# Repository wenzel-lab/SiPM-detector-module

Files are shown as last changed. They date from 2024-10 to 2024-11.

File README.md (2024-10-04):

# Open Source Hardware Silicon Photomultiplier (SiPM) Module 

Introduction... work in progress...

Follow us! [#twitter](https://twitter.com/WenzelLab), [#YouTube](https://www.youtube.com/@librehub), [#LinkedIn](https://www.linkedin.com/company/92802424), [#instagram](https://www.instagram.com/wenzellab/), [#Printables](https://www.printables.com/@WenzelLab), [#LIBREhub website](https://librehub.github.io), [#IIBM website](https://ingenieriabiologicaymedica.uc.cl/en/people/faculty/821-tobias-wenzel)

## Contribute

This is an open project in the Wenzel Lab in Santiago, Chile. If you have any suggestions to improve it or add any additional functions make a pull-request or [open an issue](https://github.com/wenzel-lab/SiPM-detector-module/issues/new).
For interactions in our team and with the community applies the [GOSH Code of Conduct](https://openhardware.science/gosh-2017/gosh-code-of-conduct/).

## License

[CERN OHL 2W](LICENSE) © FRANCISCO JAVIER MARTINEZ CATALDO and Tobias Wenzel. This project is Open Source Hardware - please acknowledge us when using the hardware or sharing modifications.

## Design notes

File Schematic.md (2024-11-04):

# Schematic of Circuit

For the preamplification stage, there are two options: design a transimpedance amplifier (TIA) or an inverting amplifier. Based on this, an operational amplifier is selected considering the following 3 criteria: *a unity-gain bandwidth of at least 1 GHz, input voltage noise less than 5 nV/√Hz, and a stable gain AV ≥ 10*. An operational amplifier with these characteristics can be used to amplify the SiPM signal with a pulse width of a few tens of nanoseconds without introducing significant noise at the 50 Ω output.

**1.- Transimpedance Amplifier TIA:** A TIA is an amplifier that converts an input current signal into a voltage signal. It is commonly used in applications where the input signal is current, such as in SiPM. For its design, the following equations must be considered to calculate the feedback capacitance Cf and the cutoff frequency Fc at a given gain. For more information you can review this [article](https://www.ti.com/lit/an/sboa122/sboa122.pdf). 

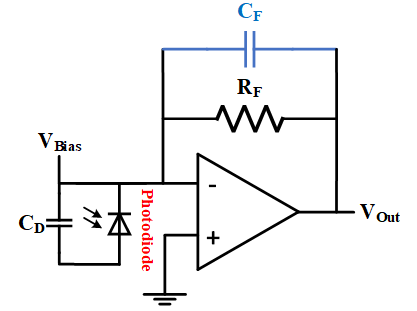
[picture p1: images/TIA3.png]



>! **Caution** 
>!
>! From the equations, it can be determined that higher gain results in lower bandwidth and a smaller optimal value for Cf, which is recommended to be greater than 1 pF. Values smaller than this begin to be significantly affected by the parasitic capacitances of the PCB. Additionally, you must consider the minimum gain at which the selected amplifier is stable.

**2.- Inverting Amplifier:** An inverting amplifier is a configuration where the input signal from SiPM is applied to the inverting input of the operational amplifier, while the non-inverting input is grounded. For its design, the following equations must be considered to calculate the feedback resistance Rf and bandwidth. The higher the gain, the lower the bandwidth. For a gain of AV = 10, the bandwidth is reduced to 150 MHz if GBP of amplifier is 1.5GHz. 

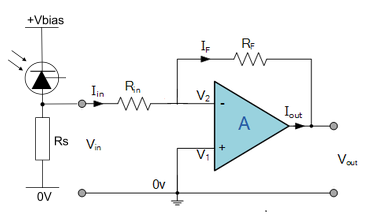
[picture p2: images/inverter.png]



>i **Note** 
>i
>i You can add a feedback capacitance Cf in parallel with the feedback resistor Rf. This way, the amplifier will also function as a low-pass filter, with a cutoff frequency Fc=1/(2PiRfCf). It is recommended to use the amplifier with a ±Vcc supply. Otherwise, if only a +Vcc source is used, you must generate an offset and decouple the amplifier's input from the SiPM output with a capacitor.

**3.- Non-inverting amplifier:** The non-inverting amplifier has a higher gain than the inverting amplifier, but its bandwidth is limited. For the proper use of the amplifier, you must cancel the bias currents by incorporating a resistance Rt at the + input pin of the amplifier, which is calculated using the following equation.

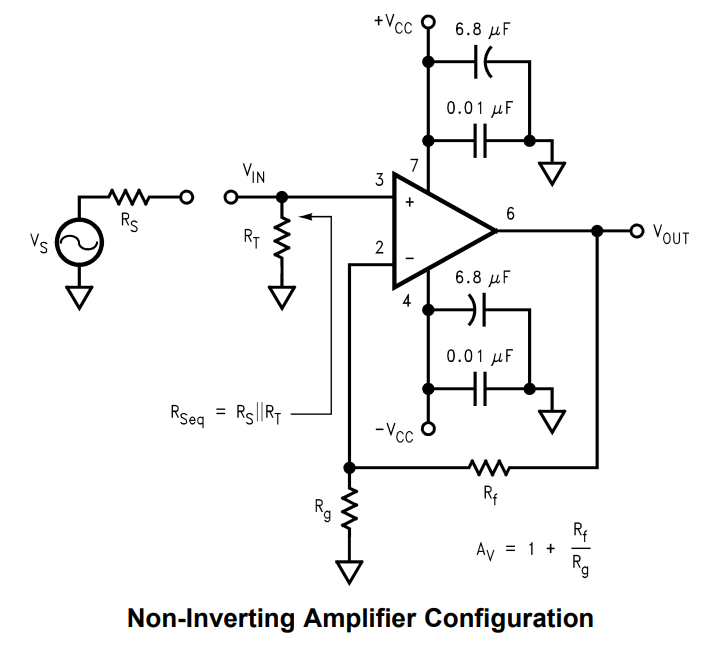
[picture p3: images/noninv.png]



>i **Note** 
>i
>i For the inverting amplifier, it is also recommended to add a resistor at the + pin to ground to cancel the bias currents. This resistor is obtained from Rf//Rin.

**4.- Final design:** A circuit is designed to allow testing of either the TIA topology or an inverting amplifier in the preamplification stage, followed by an amplification stage with a non-inverting amplifier. You can download the schematic from [here](doc/Sheet_SiPM.SchDoc). (It includes the power supply circuit, as it will be part of the same PCB).

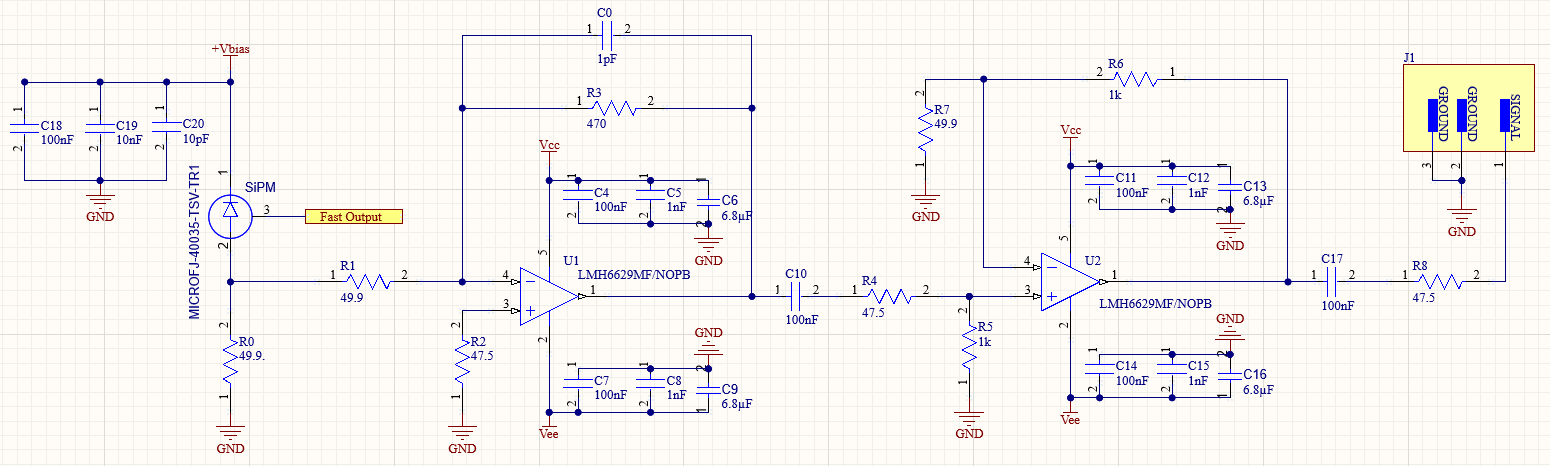
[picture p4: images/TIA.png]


|  Topology | R0[Ω] | R1[Ω] | R2[Ω] | R3[Ω] | C0 [pF] |
|:---:|:---:|:---:|:---:|:---:|:---:|
| TIA | NC |  0  | 10 | 1k | 1 |
| Inverter |  49.9 |  49.9  | 47.5 | 511 | 2 |

>i **Note** 
>i
>i The amplification stage can be omitted if from preamplification stage the pulses have enough amplitude. This depends on the number of photons that will hit the sensitive area of the SiPM and the gain of the photomultiplier, which is proportional to the size of the pixel.

Additionally, the circuit was simulated with the real components to determine the stability of the signal amplifier of the SiPM under different conditions. You can download the PSpice project by clicking [here](doc/project_sipm-PSpiceFiles.rar) 

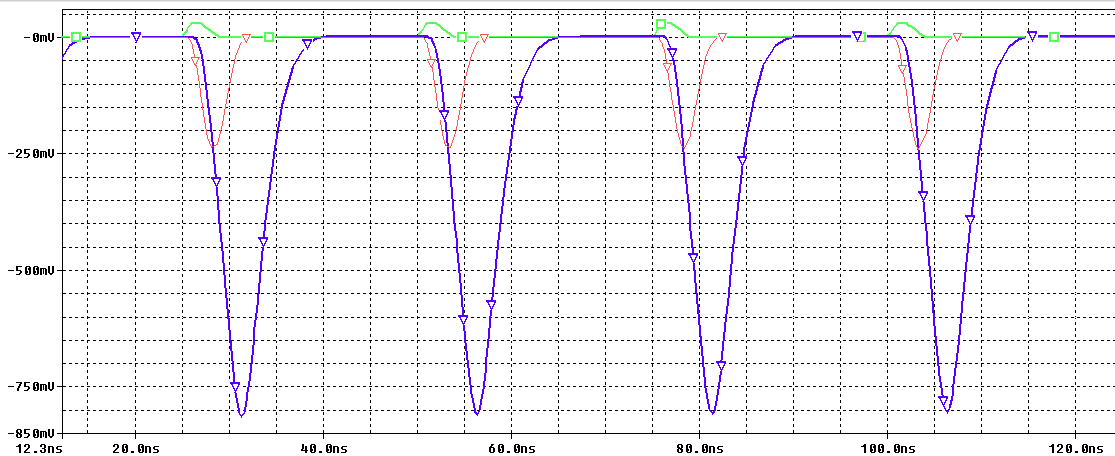
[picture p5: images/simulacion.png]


The green curve corresponds to the SiPM pulse, the red curve is the output of the preamplifier, and the blue curve is the output of the non-inverting amplifier. **Consider that the amplitude of the SiPM pulse will depend on the light incident on its sensitive area.**

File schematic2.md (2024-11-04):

# General Schematic

The circuit is divided into 2 sections detailed below. You can download the schematic from [here](doc/Sheet_SiPM.SchDoc). (It includes the readout circuit, as it will be part of the same PCB).

## 1. Boost Converter

The [MP3216](https://www.monolithicpower.com/en/documentview/productdocument/index/version/2/document_type/Datasheet/lang/en/sku/MP3216/document_id/1113) integrated circuit is chosen as the boost converter for this design. Key components such as inductor 33uH, capacitors, and feedback resistors are used to regulate and stabilize the voltage. The MP3216 is well-suited for compact designs and efficient power conversion, ensuring a steady voltage supply to the SiPM bias system.

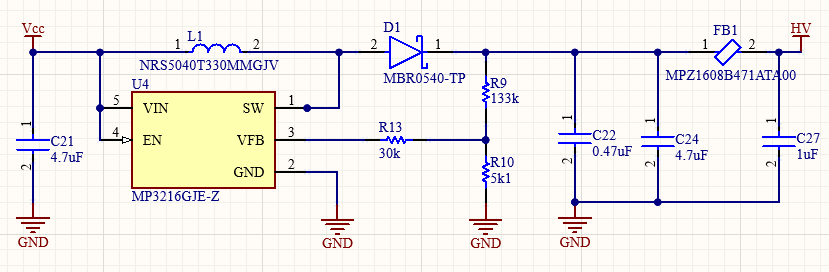
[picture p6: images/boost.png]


>i **Note** 
>i
>i An RC filter is added at the output of the converter to reduce voltage ripple to 1mVpp. Instead of a standard resistor, a ferrite model [MPZ1608B](https://product.tdk.com/en/system/files/dam/doc/product/emc/emc/beads/catalog/beads_commercial_power_mpz1608_en.pdf) is used. Its DC resistance is only 150mΩ, and at the 1MHz switching frequency, its impedance is approximately 75Ω.

## 2. Controllable Amplifier 

The cost-optimized operational amplifier model [TLV9351](https://www.ti.com/lit/ds/symlink/tlv9354.pdf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)  is selected, which can be powered with up to 40V (HV point). It is configured to have a gain of x10 with respect to the voltage Vctrl. Then, an RC filter is added to eliminate high-frequency noise to obtain an appropriate bias voltage (Vbias point) for the SiPM. Finally, a buffer model [MCP6006](https://ww1.microchip.com/downloads/aemDocuments/documents/APID/ProductDocuments/DataSheets/MCP6006-6R-6U-7-9-Data-Sheet-20006411B.pdf) with high input impedance is included, allowing monitoring of the high voltage (V_HV point).  
 
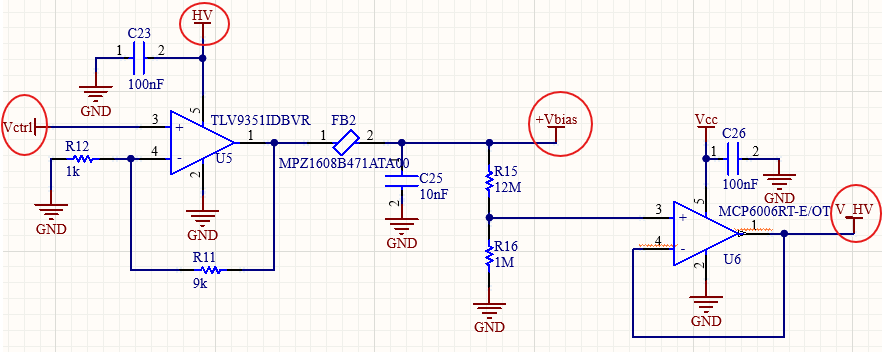
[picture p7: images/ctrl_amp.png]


The voltage ranges for each point are as follows:

|  Vctrl [V] | HV [V] | +Vbias [V] | V_HV [V] |
|:---:|:---:|:---:|:---:|
| 0 - 3.3 | 33 | 0 - 33 | 0 - 2.54 |

>
>!! **Warning** 
>!!
>!! You should limit the control voltage Vctrl depending on the maximum operating voltage of the selected SiPM. For example, if the maximum operating voltage is 30.7V, then the Vctrl voltage should not exceed 3.07V. Additionally, for high voltage monitoring, it is recommended to use an ADC with at least 12 bits, allowing Vbias adjustments with a resolution of ±10mV.
>

>i **Note** 
>i
>i Consider that the gain of SiPMs is dependent on ambient temperature, with a Vbias adjustment factor between 20-30mV/°C. Specifically, if the temperature increases, the gain will decrease, so you should to know what voltage amplitudes you will consider in your experiment. If you want to differentiate fluorescence levels, you should include temperature monitoring and adjust the control voltage Vctrl accordingly. 
>

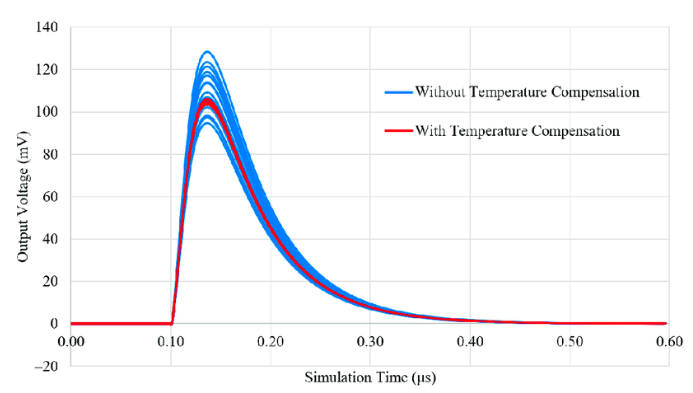
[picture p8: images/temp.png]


***Reference:** Nile E. J. Dixon et al. "Compact Back-End Electronics with Temperature Compensation and Efficient Data Management for In Situ SiPM-Based Radiation Detection",  Sensors 2023.*

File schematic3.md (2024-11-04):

# TSV Pin Adapter board

An adapter board for the SiPM is designed to allow easy connection between the silicon photomultiplier 4x4mm TSV(Through Silicon Via) and the readout. You can download the schematic and the PCB layout from [here](doc/adapt_board.zip)

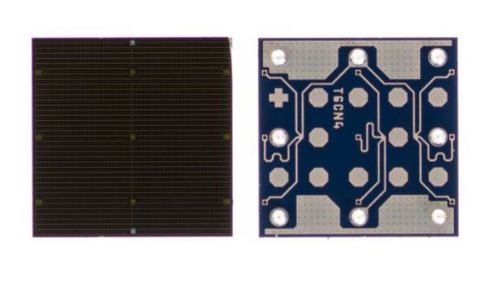
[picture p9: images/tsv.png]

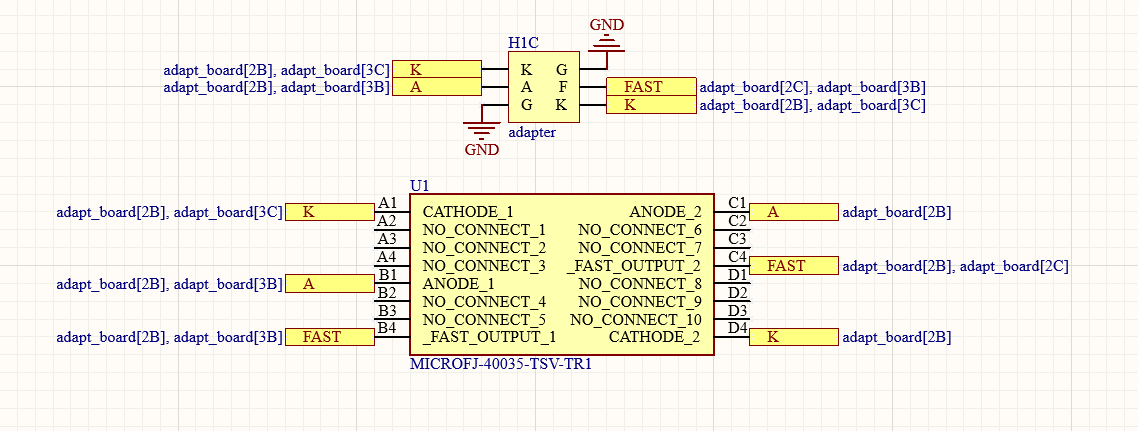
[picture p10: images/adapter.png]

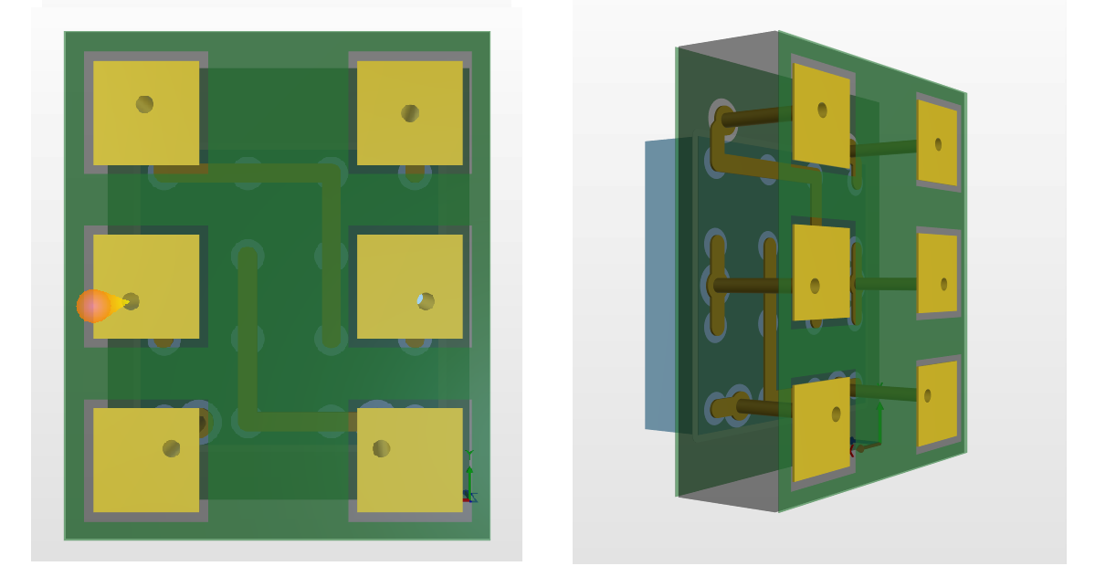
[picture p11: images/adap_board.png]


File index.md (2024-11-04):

# SiPM Module detector

This is our open-source hardware and custom electronics solution for SiPM module detector. It is used as part of "Ritmos,” our Real-time Technology for Microfluidic Droplet Sorting, as well as other microfluidics development projects. We implemented a board that includes the readout system to amplify SiPM signals to a measurable voltage with ultra-low noise, allowing the detection of a single photon. Additionally, a controllable voltage source is included, which enables the SiPM to be biased at different operating voltages. The readout provides a fast output with higher temporal resolution and a standard 50-ohm output with greater energy resolution. The SiPM detector module works with a single +5V power supply and a control voltage (Vctrl) in the range of 0-3.3V, allowing adjustment of the final SiPM bias voltage.

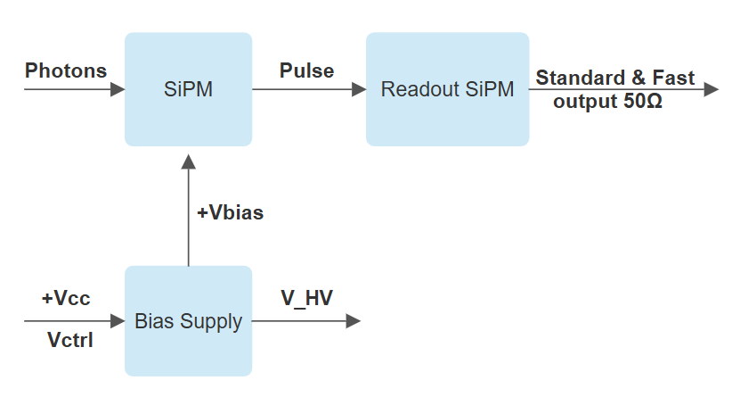
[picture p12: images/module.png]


To explore the documentation, please use the links below:

- [SiPM](testpage7.md)
	- [Go to TSV_Pin_Adapter_board](schematic3.md#TSV_Pin_Adapter_board)
- [Readout SiPM](testpage1.md)
	- [Go to Schematic_Redout_SiPM](Schematic.md#Schematic_Redout_SiPM)
- [Bias Supply](testpage5.md)
	- [Go to Schematic_Controllable_Bias_Supply](schematic2.md#Controllable_Schematic_Bias_Supply)

## References

>i **Note:** This system builds upon resources from:
>i 
>i 1.- *Giancarlo Barbarino et al. "Silicon Photo Multipliers Detectors Operating in Geiger Regime: an Unlimited Device for Future Applications", [Photodiodes](https://www.intechopen.com/chapters/17225) (2011)*
>i
>i 2.- *Brae V Petersen et al. "Silicon Photomultipliers as a Low-Cost Fluorescence Detector for Capillary Electrophoresis", [Anal Chem](https://pmc.ncbi.nlm.nih.gov/articles/PMC7728455/#SD1) 2020*

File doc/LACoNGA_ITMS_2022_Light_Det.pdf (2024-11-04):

## Light Detection with SiPMs

by Dennis Cazar Ramírez

March 23, 2022

by Dennis Cazar Ramírez | Light Detection with SiPMs | March 23, 2022 | 1 / 22

## Contents

1 | Light - Matter Interaction Cherenkov Radiation Photoelectric effect
2 | Photomultipliers Basic Concepts Pros and Cons
3 | SiPMs Basic Concepts Photo-electron Spectrum Performance Parameters Afterpulsing Dark Count Rate Optical Crosstalk
4 | Conclusions
by Dennis Cazar Ramírez | Light Detection with SiPMs | March 23, 2022 | 2 / 22

## Light - Matter Interaction

Introduction

Let´s focus in two scenarios:

Charged particles vs matter: Ionization, Cherenkov Effect, Bremsstrahlung
Photons vs matter: Photoelectric Effect, Compton effect, pair production

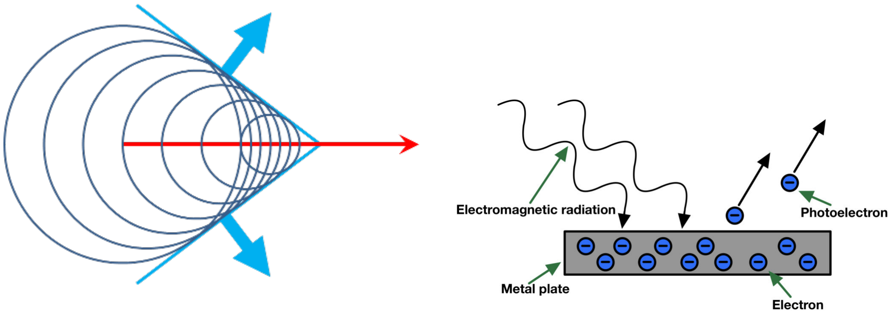
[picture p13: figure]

Cherenkov effect produces light (UV photons) while Photoelectric effect produces photo-electrons

by Dennis Cazar Ramírez | Light Detection with SiPMs | March 23, 2022 | 3 / 22

## Cherenkov Effect

Basic Concepts

Cherenkov radiation is electromagnetic radiation emitted when a charged particle (such as a muon) passes through a dielectric medium at a speed greater than the speed of light in that medium.

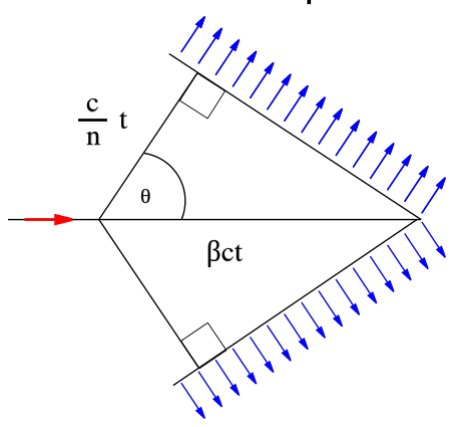
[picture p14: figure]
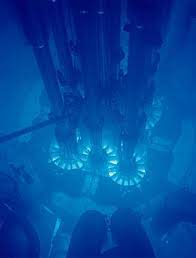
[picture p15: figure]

Its cause is similar to the cause of a sonic boom, the sharp sound heard when faster-than-sound movement occurs.
β the ratio between the speed of the particle and the speed of light The emitted light waves travel at speed ve = c/n
the emission angle results in cosθ = 1/nβ
by Dennis Cazar Ramírez | Light Detection with SiPMs | March 23, 2022 | 4 / 22

## Cherenkov Effect

Applications

A Water Cherenkov Detector WCD is used to detect relativistic particles (muons, electrons even neutrinos)

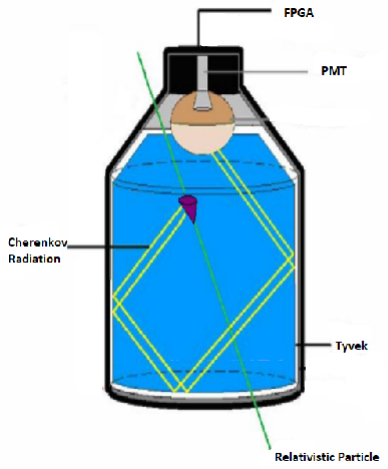
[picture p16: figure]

Cherenkov radiation is detected by a Photomultiplier PMT and converted into electric current
This signal is digitized and processed by an FPGA
by Dennis Cazar Ramírez | Light Detection with SiPMs | March 23, 2022 | 5 / 22

## Photoelectric effect

Basic Concepts

The photoelectric effect is the emission of electrons when electromagnetic radiation, such as light, hits a material. Electrons emitted in this manner are called photo-electrons.
In 1905, Einstein proposed a theory of the photoelectric effect using a concept first put forward by Max Planck that light consists of tiny packets of energy known as photons or light quanta.

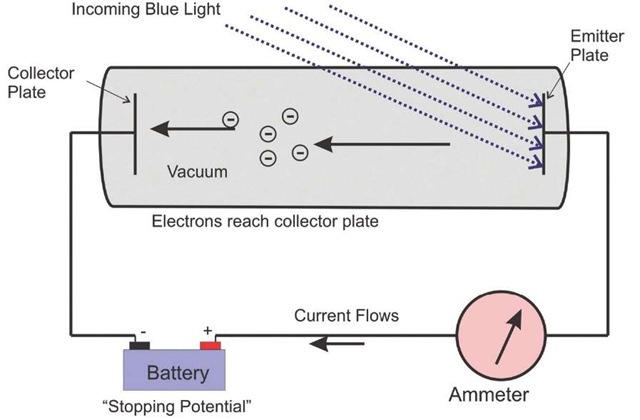
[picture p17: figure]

Kinetic energy of the emitted photo-electron is K = h(f − fo

The emitted photo-electron can be accelerated by an external electric field

by Dennis Cazar Ramírez | Light Detection with SiPMs | March 23, 2022 | 6 / 22

## Photomultipliers

Basic Concepts

These are extremely light-sensitive vacuum tubes with a coated photocathode inside the envelope.
By means of a series of electrodes (dynodes) at ever-higher potentials, these electrons are accelerated and substantially increased in number through secondary emission to provide a readily detectable output current.

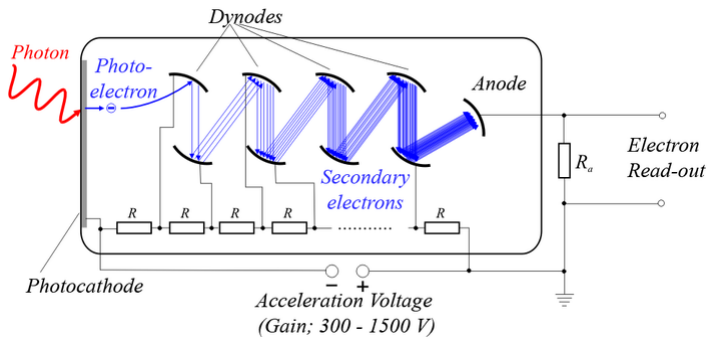
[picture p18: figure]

Photomultipliers are still commonly used wherever low levels of light must be detected

by Dennis Cazar Ramírez | Light Detection with SiPMs | March 23, 2022 | 7 / 22

## Photomultipliers

Pros and Cons

Pros
PMTs are extremely sensitive detectors of light (UV, visible, and near-IR)
PMTs amplification is as much as 10⁸
(i.e. 160 dB!!!)
They have low noise and fast response

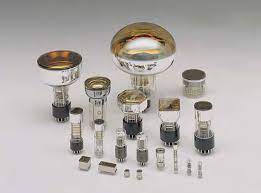
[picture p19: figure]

Cons
PMTs need High Voltage HV (300 to 2000 V) sources to operate. PMTs are sensitive to Magnetic Fields
Very expensive and delicate
by Dennis Cazar Ramírez | Light Detection with SiPMs | March 23, 2022 | 8 / 22

## Silicon Photo-multipliers

Basic concepts

The Silicon Photomultiplier (SiPM) is a sensor that addresses the challenge of sensing, timing and quantifying low-light signals down to the single-photon level
The SiPM features low-voltage operation, insensitivity to magnetic fields, mechanical robustness and excellent uniformity of response

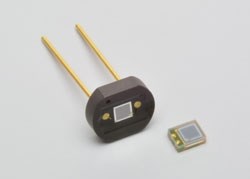
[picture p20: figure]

When a photon travels through silicon, it may be absorbed and transfer energy to a bound electron. This absorbed energy causes the electron to move from the valence band into the conduction band, creating an electron-hole pair.

by Dennis Cazar Ramírez | Light Detection with SiPMs | March 23, 2022 | 9 / 22

## Silicon Photo-Multipliers

Photodiodes

A photodiode is formed by a silicon p-n junction that creates a depletion region that is free of mobile charge carriers.

When a photon is absorbed in silicon it will create an electron-hole pair.
Applying a reverse bias to a photodiode sets up an electric field across the depletion region that will cause these charge carriers to be accelerated towards the anode (holes), or cathode (electrons).

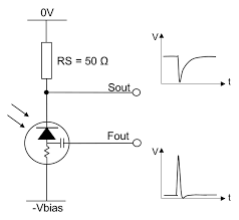
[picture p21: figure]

by Dennis Cazar Ramírez | Light Detection with SiPMs | March 23, 2022 | 10 / 22

## Silicon Photomultipliers

Schematic

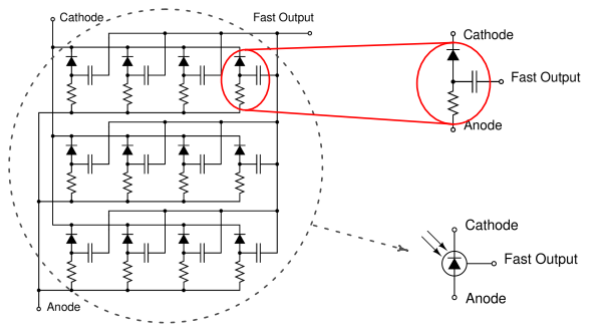
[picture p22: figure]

Simplified Circuit Schematic of a SiPM showing each Microcell which is Composed of the SPAD (Single Photon Avalanche Diode)

by Dennis Cazar Ramírez | Light Detection with SiPMs | March 23, 2022 | 11 / 22

## Silicon Photomultipliers

Pulse shape

The response to low-level light pulses of an reverse biased SiPM is

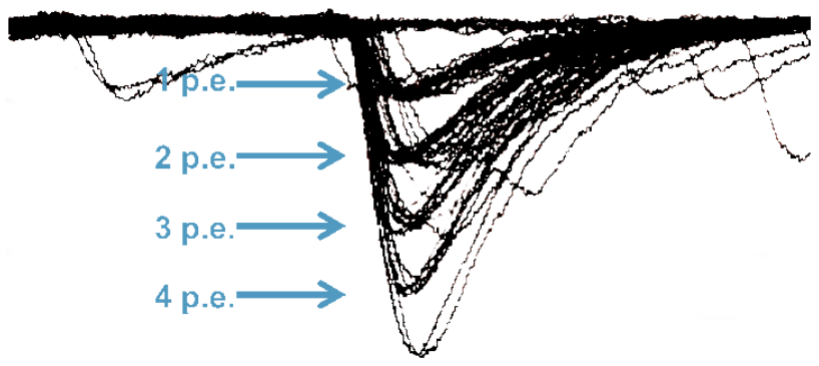
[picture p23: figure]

The sensor output is a photocurrent, and the total charge Q generated from an event is given by,

Q = Nfired · G · q

Where G is the gain and q is the electron charge

by Dennis Cazar Ramírez | Light Detection with SiPMs | March 23, 2022 | 12 / 22

## Photo-electron Spectrum

The total charge is also equal to the integral of the photo-current pulse

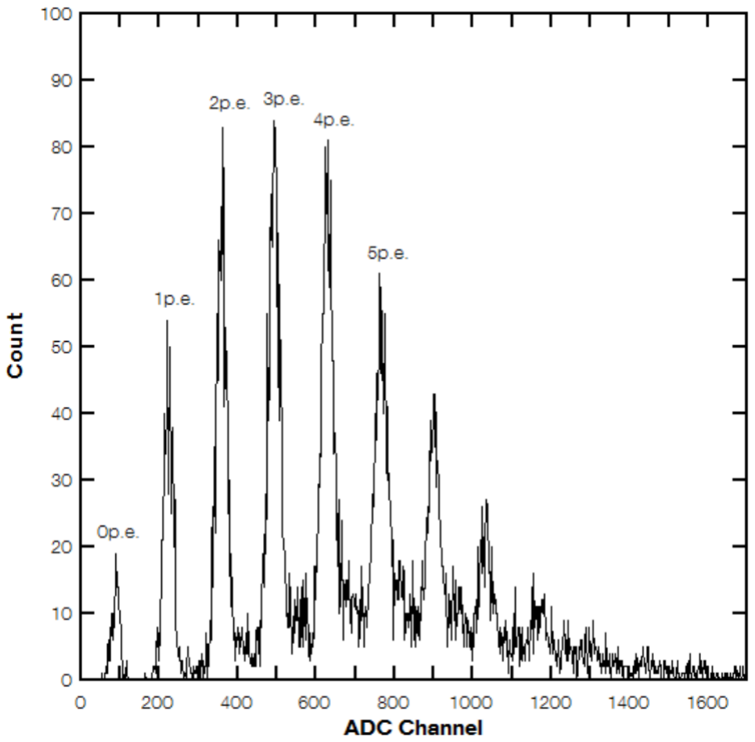
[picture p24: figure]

Achieved using Brief, Low-level Light Pulses

by Dennis Cazar Ramírez | Light Detection with SiPMs | March 23, 2022 | 13 / 22

## Performance Parameters

Breakdown Voltage and Overvoltage

The breakdown voltage (Vbr) is the bias point at which the electric field strength generated in the depletion region is sufficient to create a Geiger discharge.


Bias Voltage is Vbias = Vbr + ∆V
∆V is the Overvoltage


Vbr and ∆V are given in product’s datasheet

by Dennis Cazar Ramírez | Light Detection with SiPMs | March 23, 2022 | 14 / 22

## Performance Parameters

Gain

The gain of an SiPM sensor is defined as the amount of charge created for each detected photon, and is a function of overvoltage and microcell size
G =

C · ∆V
q

If the charge from each pulse is integrated and a charge spectrum is formed, the peaks due to successive numbers of detected photons will be clearly visible
The separation between each pair of adjacent peaks (in pC) is constant and corresponds to the charge generated from a single fired microcell.
This can therefore be used to accurately calculate the gain, using the equation above.
by Dennis Cazar Ramírez | Light Detection with SiPMs | March 23, 2022 | 15 / 22

## Performance Parameters

Photon Detection Efficiency and Responsivity

The photon detection efficiency (PDE) is a measure of the sensitivity of an SiPM and is a function of wavelength of the incident light, the applied overvoltage and microcell fill factor


The PDE differs slightly from the quantum efficiency (QE) that is quoted for a PMT or APD

by Dennis Cazar Ramírez | Light Detection with SiPMs | March 23, 2022 | 16 / 22

## Performance Parameters

Photon Detection Efficiency and Responsivity

The PDE is the statistical probability that an incident photon interacts with a microcell to produce an avalanche, and is defined as:

PDE(λ, V) = η(λ) · ε(V) · F

where η(λ) is the quantum efficiency of silicon, ε(V) is the avalanche initiation probability and F is the fill factor of the device
The quantum efficiency is a measure of the likelihood of an incident photon creating an electron-hole pair in the sensitive volume of the sensor.
The responsivity is defined as the average photocurrent produced per unit optical power and is given by:

R =

Ip

Pop

where Ip is the measured photocurrent and Pop is the incident optical power at a particular wavelength over the sensor area.

by Dennis Cazar Ramírez | Light Detection with SiPMs | March 23, 2022 | 17 / 22

## Afterpulsing

During breakdown, carriers can become trapped in defects in the silicon.
After a delay of up to several ns, the trapped carriers are released, potentially initiating an avalanche and creating an afterpulse in the same microcell.


Afterpulses with short delay that occur during the recovery time of the microcell tend to have negligible impact as the microcell is not fully charged. However, longer delay afterpulses can impact measurements with the SiPM if the rate is high

by Dennis Cazar Ramírez | Light Detection with SiPMs | March 23, 2022 | 18 / 22

## Dark Count Rate

Noise in SiPMs

The main source of noise in an SiPM is the dark count rate (DCR), which is primarily due to thermal electrons generated in the active volume. The DCR is a function of active area, overvoltage and temperature


Since the dark count is comprised of a series of pulses, its magnitude is quoted as a pulse rate (kHz)

by Dennis Cazar Ramírez | Light Detection with SiPMs | March 23, 2022 | 19 / 22

## Optical Crosstalk

Noise in SiPMs

During avalanche, accelerated carriers in the high field region will emit photons that can initiate a secondary avalanche in a neighboring microcell.
These secondary photons tend to be in the near infrared (NIR) region and can travel substantial distances through the silicon


Optical Crosstalk increases with overvoltage

by Dennis Cazar Ramírez | Light Detection with SiPMs | March 23, 2022 | 20 / 22

## SiPM advantages

The SiPM has high gain (10⁶
) and PDE (> 50%) combined with the physical benefits of compactness, ruggedness and magnetic insensitivity.
In addition, the SiPM achieves its high gain with very low bias voltage ( 50V) and the noise is almost entirely at the single photon level.

Because of the high degree of uniformity between the microcells the SiPM is capable of discriminating the precise number of photons detected as distinct, discrete levels at the output node
The ability to measure a well resolved photoelectron spectrum is a feature of the SiPM which is generally not possible with PMTs due to the variability in the gain, or excess noise
Some SiPM models can detect radiation (X, γ) directly
by Dennis Cazar Ramírez | Light Detection with SiPMs | March 23, 2022 | 21 / 22

## References

Hamamatsu PMTs (https://www.hamamatsu.com/us/en/product/optical-sensors/pmt.html)
Multi-Pixel Photon Counters (https://www.hamamatsu.com/us/en/product/optical-sensors/mppc.html) On-semi SiPM application notes (https://www.onsemi.com/design/resources/design-resources/appnotes?rpn=C-SERIES%20SIPM)
by Dennis Cazar Ramírez | Light Detection with SiPMs | March 23, 2022 | 22 / 22

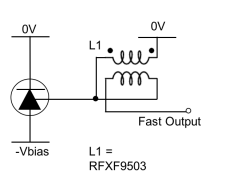
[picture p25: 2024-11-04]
images/fast.png

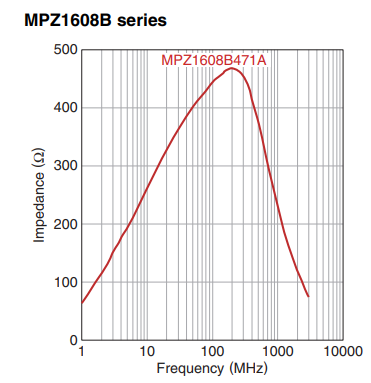
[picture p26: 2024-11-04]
images/mpz1608b.png

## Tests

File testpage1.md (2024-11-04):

# Redout SiPM

A two-stage amplifier is designed to detect up to a single photon with high bandwidth. It includes a fast output with higher temporal resolution and a standard output with higher energy resolution, allowing for differentiation of the number of photons being detected.

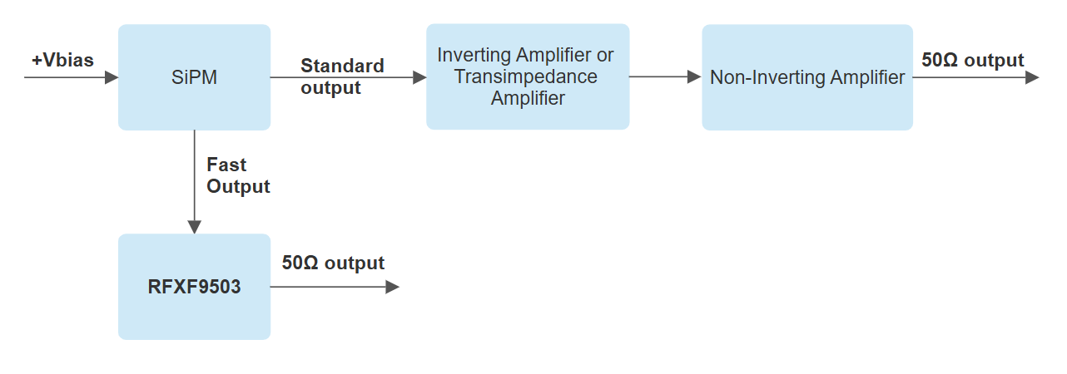
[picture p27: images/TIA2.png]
 

## Design Specifications

These instructions will guide you on how to design and assemble the readout of SiPM. You can access the project by clicking here **[SiPM Detector Module]( https://github.com/wenzel-lab/SiPM-detector-module)**

* [Schematic_Redout_SiPM](Schematic.md){step}

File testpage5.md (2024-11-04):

# Bias Supply

This circuit generates a continuous voltage of up to 33V to bias a silicon photomultiplier (SiPM). The first stage amplifies the input voltage using a boost converter, supplying power to a high-voltage operational amplifier. This amplifier is configured with a gain of 10 relative to a control signal (Vctrl) with a voltage range according to LVTLL standard (0 - 3.3V). This setup provides a controllable bias voltage across the full SiPM operation range. Additionally, a buffer is included for monitoring the high voltage (V_HV) set by the user.

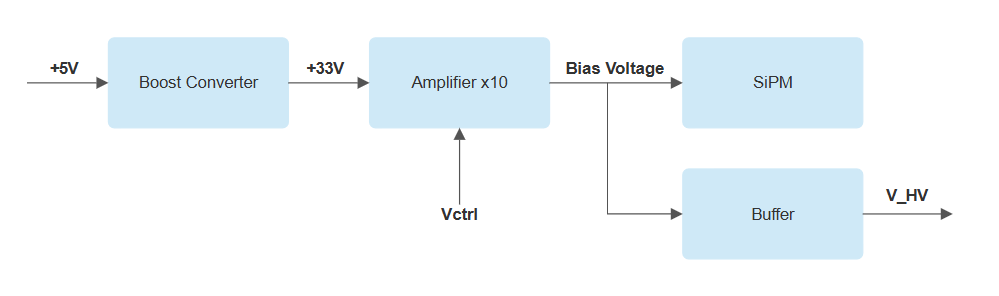
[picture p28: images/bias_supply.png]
 

## Design Specifications

These instructions will guide you on how to design and assemble the bias supply for SiPM. You can access the project by clicking here **[SiPM Detector Module]( https://github.com/wenzel-lab/SiPM-detector-module)**

* [Schematic_Controllable_Bias_Supply](schematic2.md){step}

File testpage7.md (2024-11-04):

# Silicon Photomultipliers

Silicon Photomultipliers (SiPMs) are silicon-based photomultipliers capable of detecting individual photons. They are primarily used in low-light detection applications, such as particle physics, radiation detection, among others. If you would like more information, you can access this [site](https://hub.hamamatsu.com/us/en/technical-notes/mppc-sipms/what-is-an-SiPM-and-how-does-it-work.html).

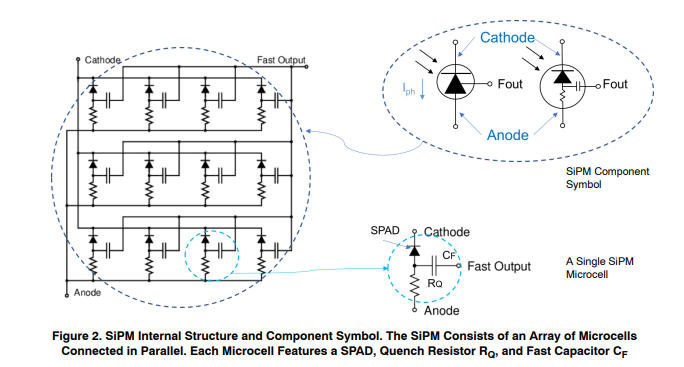
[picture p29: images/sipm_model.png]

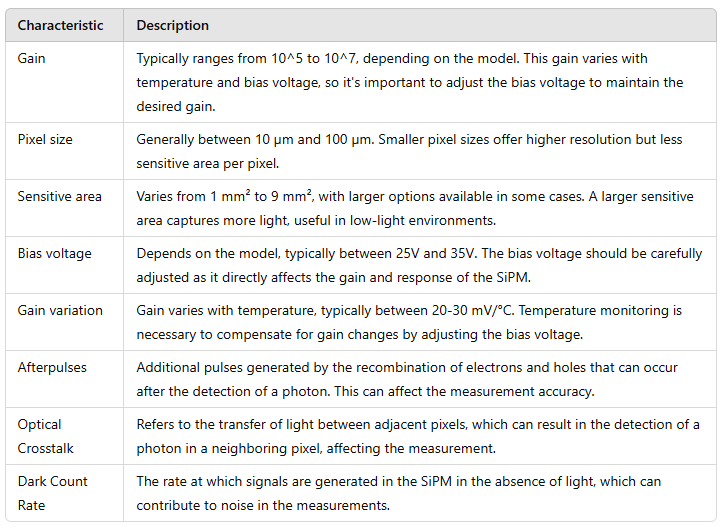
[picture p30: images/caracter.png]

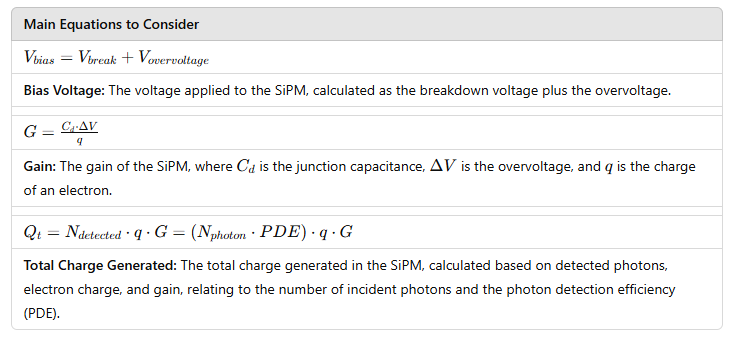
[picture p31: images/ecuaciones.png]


In the article of Brae V. Petersen et al. different SiPMs (9 mm² and 36 mm²) and microcell sizes (35 μm and 50 μm) were evaluated to determine their limit of detection (LOD) and dynamic range compared to photomultiplier tubes (PMTs). The results demonstrated that the SiPMs can detect fluorescein across a concentration range of 10^-12 to 10^-5 M, achieving performance characteristics comparable to those of PMTs.

The 36 mm² SiPM exhibited the highest sensitivity but also experienced saturation at higher concentrations. In contrast, the 9 mm² SiPM with 35 μm microcells showed a better dynamic range, attributed to its shorter dead time. This allows for a quicker response to successive signals and improved resolution in event detection, minimizing signal overlap and optimizing data collection in high event frequency situations.

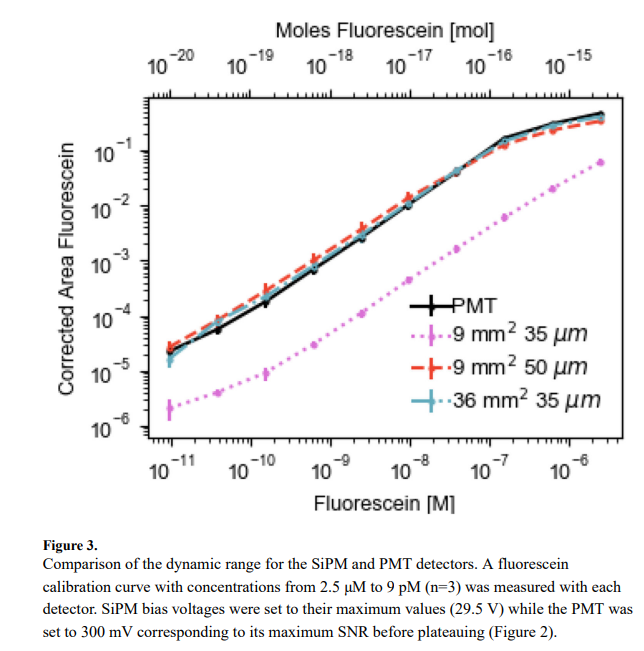
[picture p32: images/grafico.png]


Considering the above, the SiPM model [MICROFJ-40035-TSV-TR1](https://www.onsemi.com/pdf/datasheet/microj-series-d.pdf) has been chosen, which features a sensitive area of 16 mm² and pixels of 35 μm. This way, sensitivity is increased without significantly reducing the dynamic range compared to a 36 mm² SiPM.

## Design Specifications

These instructions will guide you on how to design and assemble the SiPM.  You can access the project by clicking here **[SiPM Detector Module]( https://github.com/wenzel-lab/SiPM-detector-module)**

* [TSV_Pin_Adapter_board](schematic3.md){step}
